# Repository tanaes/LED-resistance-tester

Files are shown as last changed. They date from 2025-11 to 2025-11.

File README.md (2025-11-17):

# LED-resistance-tester
Simple PCB for dialing in current limiting resistors for LEDs

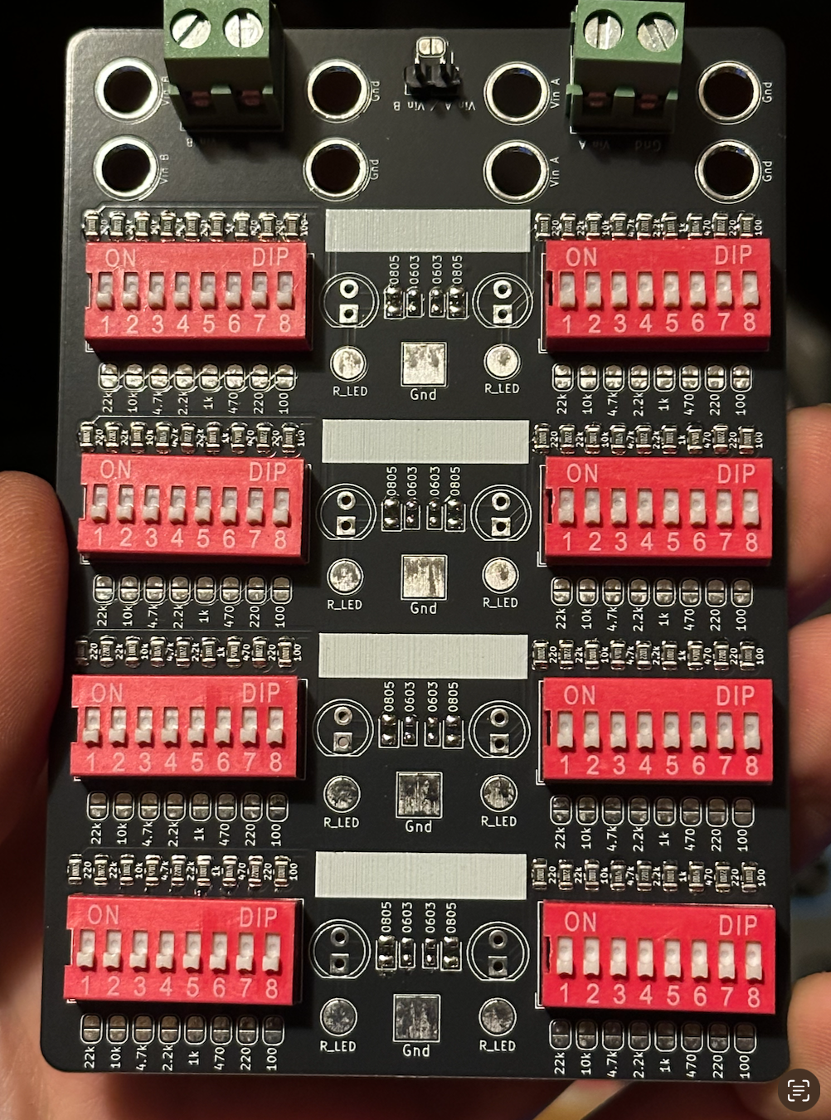
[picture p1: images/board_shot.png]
Simple photo of board


## Inspiration

This project was broadly inspired by [this blog post on Sparkfun](https://news.sparkfun.com/5461), combined of course with the unceasing voice in my head to *design another stupid PCB*. 

## Usage

I set this board up to have four LED test 'stations' each on two parallel power rails. The idea is that you can easily match your brightness on, say, 5V and 24V. There's a jumper to link the two rails, too, in case you just want to test 8 different LEDs at the same voltage. There are big, ø5mm plated holes that are just the right size for grabbing with alligator clips for powering, as well as 5mm terminal blocks. 

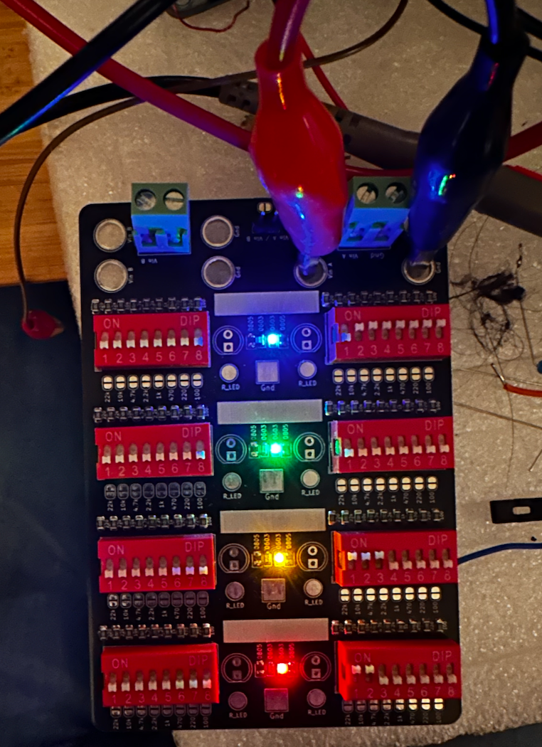
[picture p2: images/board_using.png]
Photo of board in use


LED current is set with DIP switches jumping over a ~ decadal series of common resistor values, with a minimum series resistance of 220Ω and a maximum of about 41kΩ (because DIP switches are fun).

Solder jumpers in parallel to the DIP switches offer an alternative (archival) mechanism, on the theory that one might want to dial this in for a particular vendor series and then toss it in a drawer for future reference. 

There are footprints for 0603 and 0805 SMT plus THT LEDs per channel, as well as big test pads for double-checking resistance values. 

Big white silkscreen areas are present on the front and back, in principle as a place to write down what the heck you have soldered onto the board for when you come across it in that drawer a year from now.

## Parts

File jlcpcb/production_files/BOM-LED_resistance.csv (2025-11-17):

Comment | Designator | Footprint | LCSC | Quantity
R_LED | TP14 | TestPoint_Pad_D3.0mm |  | 1
R_LED | TP5 | TestPoint_Pad_D3.0mm |  | 1
R_LED | TP6 | TestPoint_Pad_D3.0mm |  | 1
Gnd | TP20 | TestPoint_Pad_4.0x4.0mm |  | 1
Gnd | TP19 | TestPoint_Pad_4.0x4.0mm |  | 1
Gnd | TP18 | TestPoint_Pad_4.0x4.0mm |  | 1
Gnd | TP17 | TestPoint_Pad_4.0x4.0mm |  | 1
THT | D19 | LED_D5.0mm |  | 1
0805 | D20 | LED_0805_2012Metric |  | 1
0603 | D21 | LED_0603_1608Metric |  | 1
220 | R55 | R_0805_2012Metric |  | 1
22k | R56 | R_0805_2012Metric |  | 1
10k | R57 | R_0805_2012Metric |  | 1
4.7k | R58 | R_0805_2012Metric |  | 1
2.2k | R59 | R_0805_2012Metric |  | 1
1k | R60 | R_0805_2012Metric |  | 1
470 | R61 | R_0805_2012Metric |  | 1
220 | R62 | R_0805_2012Metric |  | 1
100 | R63 | R_0805_2012Metric |  | 1
SW_DIP_x08 | SW7 | SW_DIP_SPSTx08_Slide_9.78x22.5mm_W7.62mm_P2.54mm |  | 1
R_LED | TP15 | TestPoint_Pad_D3.0mm |  | 1
THT | D22 | LED_D5.0mm |  | 1
0805 | D23 | LED_0805_2012Metric |  | 1
0603 | D24 | LED_0603_1608Metric |  | 1
220 | R64 | R_0805_2012Metric |  | 1
22k | R65 | R_0805_2012Metric |  | 1
10k | R66 | R_0805_2012Metric |  | 1
4.7k | R67 | R_0805_2012Metric |  | 1
2.2k | R68 | R_0805_2012Metric |  | 1
1k | R69 | R_0805_2012Metric |  | 1
470 | R70 | R_0805_2012Metric |  | 1
220 | R71 | R_0805_2012Metric |  | 1
100 | R72 | R_0805_2012Metric |  | 1
SW_DIP_x08 | SW8 | SW_DIP_SPSTx08_Slide_9.78x22.5mm_W7.62mm_P2.54mm |  | 1
R_LED | TP16 | TestPoint_Pad_D3.0mm |  | 1
THT | D13 | LED_D5.0mm |  | 1
0805 | D14 | LED_0805_2012Metric |  | 1
0603 | D15 | LED_0603_1608Metric |  | 1
220 | R37 | R_0805_2012Metric |  | 1
22k | R38 | R_0805_2012Metric |  | 1
10k | R39 | R_0805_2012Metric |  | 1
4.7k | R40 | R_0805_2012Metric |  | 1
2.2k | R41 | R_0805_2012Metric |  | 1
1k | R42 | R_0805_2012Metric |  | 1
470 | R43 | R_0805_2012Metric |  | 1
220 | R44 | R_0805_2012Metric |  | 1
100 | R45 | R_0805_2012Metric |  | 1
SW_DIP_x08 | SW5 | SW_DIP_SPSTx08_Slide_9.78x22.5mm_W7.62mm_P2.54mm |  | 1
R_LED | TP13 | TestPoint_Pad_D3.0mm |  | 1
0603 | D18 | LED_0603_1608Metric |  | 1
THT | D16 | LED_D5.0mm |  | 1
0805 | D17 | LED_0805_2012Metric |  | 1
THT | D1 | LED_D5.0mm |  | 1
0603 | D3 | LED_0603_1608Metric |  | 1
0805 | D2 | LED_0805_2012Metric |  | 1
SW_DIP_x08 | SW1 | SW_DIP_SPSTx08_Slide_9.78x22.5mm_W7.62mm_P2.54mm |  | 1
220 | R1 | R_0805_2012Metric |  | 1
22k | R2 | R_0805_2012Metric |  | 1
10k | R3 | R_0805_2012Metric |  | 1
4.7k | R4 | R_0805_2012Metric |  | 1
2.2k | R5 | R_0805_2012Metric |  | 1
1k | R6 | R_0805_2012Metric |  | 1
470 | R7 | R_0805_2012Metric |  | 1
220 | R8 | R_0805_2012Metric |  | 1
100 | R9 | R_0805_2012Metric |  | 1
0603 | D6 | LED_0603_1608Metric |  | 1
0805 | D5 | LED_0805_2012Metric |  | 1
220 | R10 | R_0805_2012Metric |  | 1
22k | R11 | R_0805_2012Metric |  | 1
1k | R15 | R_0805_2012Metric |  | 1
220 | R17 | R_0805_2012Metric |  | 1
2.2k | R14 | R_0805_2012Metric |  | 1
SW_DIP_x08 | SW2 | SW_DIP_SPSTx08_Slide_9.78x22.5mm_W7.62mm_P2.54mm |  | 1
100 | R18 | R_0805_2012Metric |  | 1
10k | R12 | R_0805_2012Metric |  | 1
470 | R16 | R_0805_2012Metric |  | 1
THT | D4 | LED_D5.0mm |  | 1
4.7k | R13 | R_0805_2012Metric |  | 1
Vin A | J1 | TerminalBlock_Phoenix_MKDS-1,5-2-5.08_1x02_P5.08mm_Horizontal |  | 1
Gnd | TP2 | TestPoint_Plated_Hole_D5.0mm |  | 1
Vin A | TP1 | TestPoint_Plated_Hole_D5.0mm |  | 1
Vin A | TP3 | TestPoint_Plated_Hole_D5.0mm |  | 1
Gnd | TP4 | TestPoint_Plated_Hole_D5.0mm |  | 1
22k | R47 | R_0805_2012Metric |  | 1
SW_DIP_x08 | SW6 | SW_DIP_SPSTx08_Slide_9.78x22.5mm_W7.62mm_P2.54mm |  | 1
10k | R48 | R_0805_2012Metric |  | 1
220 | R53 | R_0805_2012Metric |  | 1
470 | R52 | R_0805_2012Metric |  | 1
2.2k | R50 | R_0805_2012Metric |  | 1
1k | R51 | R_0805_2012Metric |  | 1
220 | R46 | R_0805_2012Metric |  | 1
100 | R54 | R_0805_2012Metric |  | 1
4.7k | R49 | R_0805_2012Metric |  | 1
Gnd | TP12 | TestPoint_Plated_Hole_D5.0mm |  | 1
Vin B | TP11 | TestPoint_Plated_Hole_D5.0mm |  | 1
Gnd | TP10 | TestPoint_Plated_Hole_D5.0mm |  | 1
Vin B | TP9 | TestPoint_Plated_Hole_D5.0mm |  | 1
Vin A / Vin B | JP66 | PinHeader_1x02_P2.54mm_Vertical |  | 1
Vin B | J2 | TerminalBlock_Phoenix_MKDS-1,5-2-5.08_1x02_P5.08mm_Horizontal |  | 1
THT | D10 | LED_D5.0mm |  | 1
SW_DIP_x08 | SW4 | SW_DIP_SPSTx08_Slide_9.78x22.5mm_W7.62mm_P2.54mm |  | 1
220 | R35 | R_0805_2012Metric |  | 1
100 | R36 | R_0805_2012Metric |  | 1
10k | R30 | R_0805_2012Metric |  | 1
R_LED | TP8 | TestPoint_Pad_D3.0mm |  | 1
0603 | D12 | LED_0603_1608Metric |  | 1
22k | R29 | R_0805_2012Metric |  | 1
0805 | D11 | LED_0805_2012Metric |  | 1
1k | R33 | R_0805_2012Metric |  | 1
220 | R28 | R_0805_2012Metric |  | 1
4.7k | R31 | R_0805_2012Metric |  | 1
470 | R34 | R_0805_2012Metric |  | 1
2.2k | R32 | R_0805_2012Metric |  | 1
4.7k | R22 | R_0805_2012Metric |  | 1
220 | R19 | R_0805_2012Metric |  | 1
470 | R25 | R_0805_2012Metric |  | 1
100 | R27 | R_0805_2012Metric |  | 1
10k | R21 | R_0805_2012Metric |  | 1
SW_DIP_x08 | SW3 | SW_DIP_SPSTx08_Slide_9.78x22.5mm_W7.62mm_P2.54mm |  | 1
1k | R24 | R_0805_2012Metric |  | 1
0805 | D8 | LED_0805_2012Metric |  | 1
THT | D7 | LED_D5.0mm |  | 1
0603 | D9 | LED_0603_1608Metric |  | 1
220 | R26 | R_0805_2012Metric |  | 1
R_LED | TP7 | TestPoint_Pad_D3.0mm |  | 1
2.2k | R23 | R_0805_2012Metric |  | 1
22k | R20 | R_0805_2012Metric |  | 1

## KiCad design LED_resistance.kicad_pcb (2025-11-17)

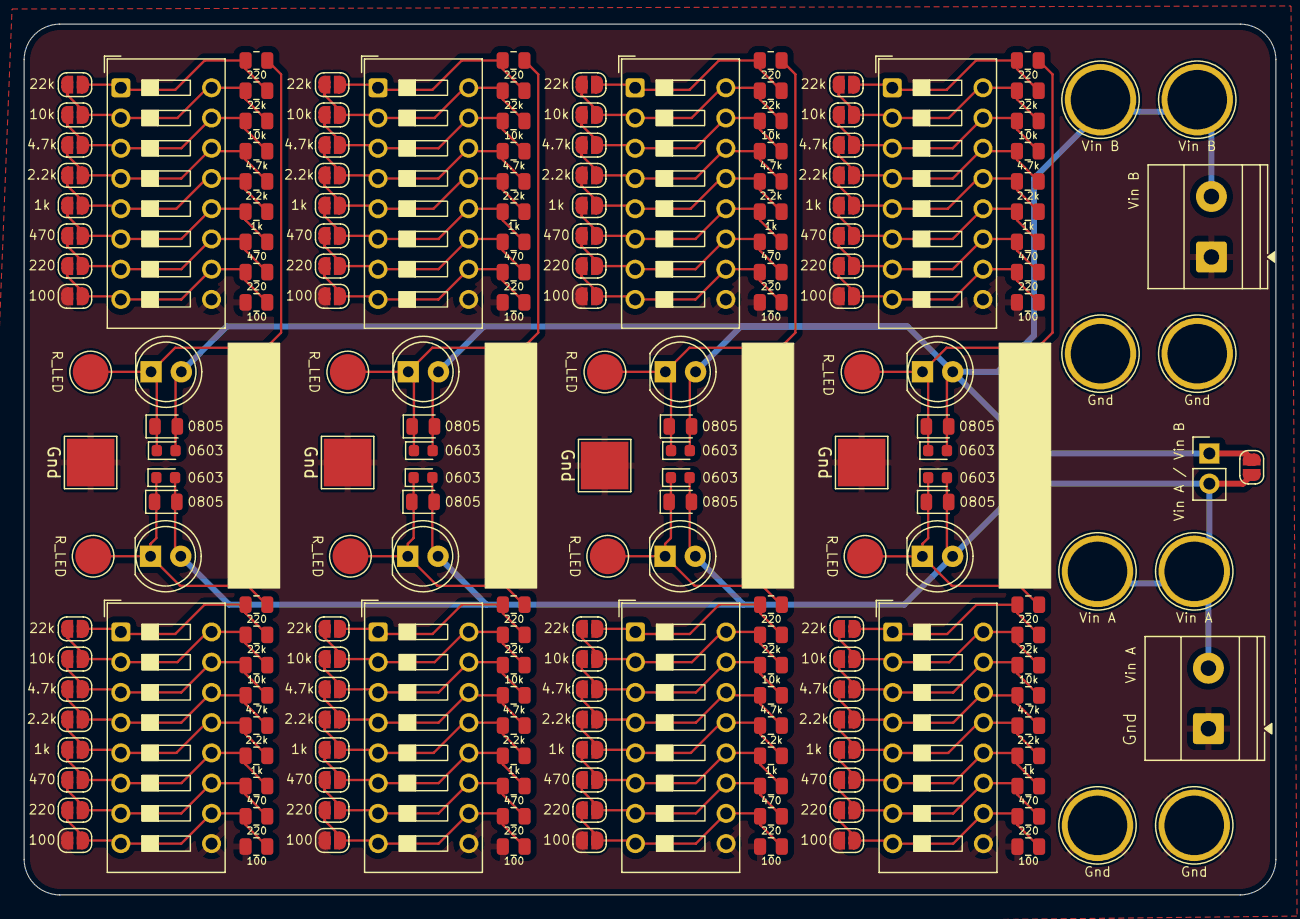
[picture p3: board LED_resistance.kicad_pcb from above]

Board: 2 copper layers, 105.2 x 73.2 mm, 192 parts (0 on the bottom side), 75 nets.

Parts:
D1, D4, D7, D10, D13, D16, D19, D22: THT; LED_D5.0mm
D2, D5, D8, D11, D14, D17, D20, D23: 0805; LED_0805_2012Metric
D3, D6, D9, D12, D15, D18, D21, D24: 0603; LED_0603_1608Metric
J1: Vin A; TerminalBlock_Phoenix_MKDS-1,5-2-5.08_1x02_P5.08mm_Horizont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
J2: Vin B; TerminalBlock_Phoenix_MKDS-1,5-2-5.08_1x02_P5.08mm_Horizont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
JP1, JP9, JP17, JP25, JP33, JP41, JP49, JP57: 22k; SolderJumper-2_P1.3mm_Open_RoundedPad1.0x1.5mm
JP2, JP10, JP18, JP26, JP34, JP42, JP50, JP58: 10k; SolderJumper-2_P1.3mm_Open_RoundedPad1.0x1.5mm
JP3, JP11, JP19, JP27, JP35, JP43, JP51, JP59: 4.7k; SolderJumper-2_P1.3mm_Open_RoundedPad1.0x1.5mm
JP4, JP12, JP20, JP28, JP36, JP44, JP52, JP60: 2.2k; SolderJumper-2_P1.3mm_Open_RoundedPad1.0x1.5mm
JP5, JP13, JP21, JP29, JP37, JP45, JP53, JP61: 1k; SolderJumper-2_P1.3mm_Open_RoundedPad1.0x1.5mm
JP6, JP14, JP22, JP30, JP38, JP46, JP54, JP62: 470; SolderJumper-2_P1.3mm_Open_RoundedPad1.0x1.5mm
JP7, JP15, JP23, JP31, JP39, JP47, JP55, JP63: 220; SolderJumper-2_P1.3mm_Open_RoundedPad1.0x1.5mm
JP8, JP16, JP24, JP32, JP40, JP48, JP56, JP64: 100; SolderJumper-2_P1.3mm_Open_RoundedPad1.0x1.5mm
JP65: SolderJumper_2_Open; SolderJumper-2_P1.3mm_Open_RoundedPad1.0x1.5mm
JP66: Vin A / Vin B; PinHeader_1x02_P2.54mm_Vertical
R1, R8, R10, R17, R19, R26, R28, R35, R37, R44, R46, R53, R55, R62, R64, R71: 220; R_0805_2012Metric
R2, R11, R20, R29, R38, R47, R56, R65: 22k; R_0805_2012Metric
R3, R12, R21, R30, R39, R48, R57, R66: 10k; R_0805_2012Metric
R4, R13, R22, R31, R40, R49, R58, R67: 4.7k; R_0805_2012Metric
R5, R14, R23, R32, R41, R50, R59, R68: 2.2k; R_0805_2012Metric
R6, R15, R24, R33, R42, R51, R60, R69: 1k; R_0805_2012Metric
R7, R16, R25, R34, R43, R52, R61, R70: 470; R_0805_2012Metric
R9, R18, R27, R36, R45, R54, R63, R72: 100; R_0805_2012Metric
SW1, SW2, SW3, SW4, SW5, SW6, SW7, SW8: SW_DIP_x08; SW_DIP_SPSTx08_Slide_9.78x22.5mm_W7.62mm_P2.54mm
TP1, TP3: Vin A; TestPoint_Plated_Hole_D5.0mm
TP2, TP4, TP10, TP12: Gnd; TestPoint_Plated_Hole_D5.0mm
TP5, TP6, TP7, TP8, TP13, TP14, TP15, TP16: R_LED; TestPoint_Pad_D3.0mm
TP9, TP11: Vin B; TestPoint_Plated_Hole_D5.0mm
TP17, TP18, TP19, TP20: Gnd; TestPoint_Pad_4.0x4.0mm

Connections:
/led_subset2/Vin: D13.2 (A), D14.2 (A), D15.2 (A), D16.2 (A), D17.2 (A), D18.2 (A), D19.2 (A), D20.2 (A), D21.2 (A), D22.2 (A), D23.2 (A), D24.2 (A), J2.2, JP65.1 (A), JP66.1 (A), TP9.1, TP11.1
/led_subset/Vin: D1.2 (A), D2.2 (A), D3.2 (A), D4.2 (A), D5.2 (A), D6.2 (A), D7.2 (A), D8.2 (A), D9.2 (A), D10.2 (A), D11.2 (A), D12.2 (A), J1.2, JP65.2 (B), JP66.2 (B), TP1.1, TP3.1
GND: J1.1, J2.1, JP8.2 (B), JP16.2 (B), JP24.2 (B), JP32.2 (B), JP40.2 (B), JP48.2 (B), JP56.2 (B), JP64.2 (B), R9.2, R18.2, R27.2, R36.2, R45.2, R54.2, R63.2, R72.2, SW1.9, SW2.9, SW3.9, SW4.9, SW5.9, SW6.9, SW7.9, SW8.9, TP2.1, TP4.1, TP10.1, TP12.1, TP17.1, TP18.1, TP19.1, TP20.1
unnamed: D1.1 (K), D2.1 (K), D3.1 (K), R1.1, TP5.1
unnamed: D4.1 (K), D5.1 (K), D6.1 (K), R10.1, TP6.1
unnamed: D7.1 (K), D8.1 (K), D9.1 (K), R19.1, TP7.1
unnamed: D10.1 (K), D11.1 (K), D12.1 (K), R28.1, TP8.1
unnamed: D13.1 (K), D14.1 (K), D15.1 (K), R37.1, TP13.1
unnamed: D16.1 (K), D17.1 (K), D18.1 (K), R46.1, TP14.1
unnamed: D19.1 (K), D20.1 (K), D21.1 (K), R55.1, TP15.1
unnamed: D22.1 (K), D23.1 (K), D24.1 (K), R64.1, TP16.1
unnamed: JP1.1 (A), R1.2, R2.1, SW1.1
unnamed: JP1.2 (B), JP2.1 (A), R2.2, R3.1, SW1.2, SW1.16
unnamed: JP2.2 (B), JP3.1 (A), R3.2, R4.1, SW1.3, SW1.15
unnamed: JP3.2 (B), JP4.1 (A), R4.2, R5.1, SW1.4, SW1.14
unnamed: JP4.2 (B), JP5.1 (A), R5.2, R6.1, SW1.5, SW1.13
unnamed: JP5.2 (B), JP6.1 (A), R6.2, R7.1, SW1.6, SW1.12
unnamed: JP6.2 (B), JP7.1 (A), R7.2, R8.1, SW1.7, SW1.11
unnamed: JP7.2 (B), JP8.1 (A), R8.2, R9.1, SW1.8, SW1.10
unnamed: JP9.1 (A), R10.2, R11.1, SW2.1
unnamed: JP9.2 (B), JP10.1 (A), R11.2, R12.1, SW2.2, SW2.16
unnamed: JP10.2 (B), JP11.1 (A), R12.2, R13.1, SW2.3, SW2.15
unnamed: JP11.2 (B), JP12.1 (A), R13.2, R14.1, SW2.4, SW2.14
unnamed: JP12.2 (B), JP13.1 (A), R14.2, R15.1, SW2.5, SW2.13
unnamed: JP13.2 (B), JP14.1 (A), R15.2, R16.1, SW2.6, SW2.12
unnamed: JP14.2 (B), JP15.1 (A), R16.2, R17.1, SW2.7, SW2.11
unnamed: JP15.2 (B), JP16.1 (A), R17.2, R18.1, SW2.8, SW2.10
unnamed: JP17.1 (A), R19.2, R20.1, SW3.1
unnamed: JP17.2 (B), JP18.1 (A), R20.2, R21.1, SW3.2, SW3.16
unnamed: JP18.2 (B), JP19.1 (A), R21.2, R22.1, SW3.3, SW3.15
unnamed: JP19.2 (B), JP20.1 (A), R22.2, R23.1, SW3.4, SW3.14
unnamed: JP20.2 (B), JP21.1 (A), R23.2, R24.1, SW3.5, SW3.13
unnamed: JP21.2 (B), JP22.1 (A), R24.2, R25.1, SW3.6, SW3.12
unnamed: JP22.2 (B), JP23.1 (A), R25.2, R26.1, SW3.7, SW3.11
unnamed: JP23.2 (B), JP24.1 (A), R26.2, R27.1, SW3.8, SW3.10
unnamed: JP25.1 (A), R28.2, R29.1, SW4.1
unnamed: JP25.2 (B), JP26.1 (A), R29.2, R30.1, SW4.2, SW4.16
unnamed: JP26.2 (B), JP27.1 (A), R30.2, R31.1, SW4.3, SW4.15
unnamed: JP27.2 (B), JP28.1 (A), R31.2, R32.1, SW4.4, SW4.14
unnamed: JP28.2 (B), JP29.1 (A), R32.2, R33.1, SW4.5, SW4.13
unnamed: JP29.2 (B), JP30.1 (A), R33.2, R34.1, SW4.6, SW4.12
unnamed: JP30.2 (B), JP31.1 (A), R34.2, R35.1, SW4.7, SW4.11
unnamed: JP31.2 (B), JP32.1 (A), R35.2, R36.1, SW4.8, SW4.10
unnamed: JP33.1 (A), R37.2, R38.1, SW5.1
unnamed: JP33.2 (B), JP34.1 (A), R38.2, R39.1, SW5.2, SW5.16
unnamed: JP34.2 (B), JP35.1 (A), R39.2, R40.1, SW5.3, SW5.15
unnamed: JP35.2 (B), JP36.1 (A), R40.2, R41.1, SW5.4, SW5.14
unnamed: JP36.2 (B), JP37.1 (A), R41.2, R42.1, SW5.5, SW5.13
unnamed: JP37.2 (B), JP38.1 (A), R42.2, R43.1, SW5.6, SW5.12
unnamed: JP38.2 (B), JP39.1 (A), R43.2, R44.1, SW5.7, SW5.11
unnamed: JP39.2 (B), JP40.1 (A), R44.2, R45.1, SW5.8, SW5.10
unnamed: JP41.1 (A), R46.2, R47.1, SW6.1
unnamed: JP41.2 (B), JP42.1 (A), R47.2, R48.1, SW6.2, SW6.16
unnamed: JP42.2 (B), JP43.1 (A), R48.2, R49.1, SW6.3, SW6.15
unnamed: JP43.2 (B), JP44.1 (A), R49.2, R50.1, SW6.4, SW6.14
unnamed: JP44.2 (B), JP45.1 (A), R50.2, R51.1, SW6.5, SW6.13
unnamed: JP45.2 (B), JP46.1 (A), R51.2, R52.1, SW6.6, SW6.12
unnamed: JP46.2 (B), JP47.1 (A), R52.2, R53.1, SW6.7, SW6.11
unnamed: JP47.2 (B), JP48.1 (A), R53.2, R54.1, SW6.8, SW6.10
unnamed: JP49.1 (A), R55.2, R56.1, SW7.1
unnamed: JP49.2 (B), JP50.1 (A), R56.2, R57.1, SW7.2, SW7.16
unnamed: JP50.2 (B), JP51.1 (A), R57.2, R58.1, SW7.3, SW7.15
unnamed: JP51.2 (B), JP52.1 (A), R58.2, R59.1, SW7.4, SW7.14
unnamed: JP52.2 (B), JP53.1 (A), R59.2, R60.1, SW7.5, SW7.13
unnamed: JP53.2 (B), JP54.1 (A), R60.2, R61.1, SW7.6, SW7.12
unnamed: JP54.2 (B), JP55.1 (A), R61.2, R62.1, SW7.7, SW7.11
unnamed: JP55.2 (B), JP56.1 (A), R62.2, R63.1, SW7.8, SW7.10
unnamed: JP57.1 (A), R64.2, R65.1, SW8.1
unnamed: JP57.2 (B), JP58.1 (A), R65.2, R66.1, SW8.2, SW8.16
unnamed: JP58.2 (B), JP59.1 (A), R66.2, R67.1, SW8.3, SW8.15
unnamed: JP59.2 (B), JP60.1 (A), R67.2, R68.1, SW8.4, SW8.14
unnamed: JP60.2 (B), JP61.1 (A), R68.2, R69.1, SW8.5, SW8.13
unnamed: JP61.2 (B), JP62.1 (A), R69.2, R70.1, SW8.6, SW8.12
unnamed: JP62.2 (B), JP63.1 (A), R70.2, R71.1, SW8.7, SW8.11
unnamed: JP63.2 (B), JP64.1 (A), R71.2, R72.1, SW8.8, SW8.10
